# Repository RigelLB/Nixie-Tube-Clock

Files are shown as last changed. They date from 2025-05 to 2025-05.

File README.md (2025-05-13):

# Nixie-Tube-Clock
This project is based on the Easy Nixie modules made by allexoK. The following link is the Hackaday page for it: https://hackaday.io/project/192446-easynixie

The circuit itself is decently simple, the version built in the photos doesn't include the capacitors but has issues with some power supplies as the lights' striking wattage (turn on wattage) is quite above the specified 10-watt power supply. The chip used for the logic is just a generic esp32. A wire connects P27 to a plate of brass on the top of the clock. As you touch the plate it will turn on for 5 seconds (specified in code).

As a fair warning, the side usb port was put there to program the esp32 without having to take it in and out of its header pins too many times; however, if the switch isn't flipped to the correct side, no power will be supplied. An alternative is to set up the esp32 to be writable OTA.

Some improvements could be made to the electrical design. If you don't prefer having an both LED's be addressible, the posts that hold up the LED's could be used as the conductor to the second plane. 

The later goal in to add OTA code uploading to the esp32, and add a setup page (via webpage) that modifies the wifi SSID and password, time zone, turn on duration, and other features. Another thing will be to move the code to freeRTOS.
Pictures (1 of 1)
Pictures (1 of 6)

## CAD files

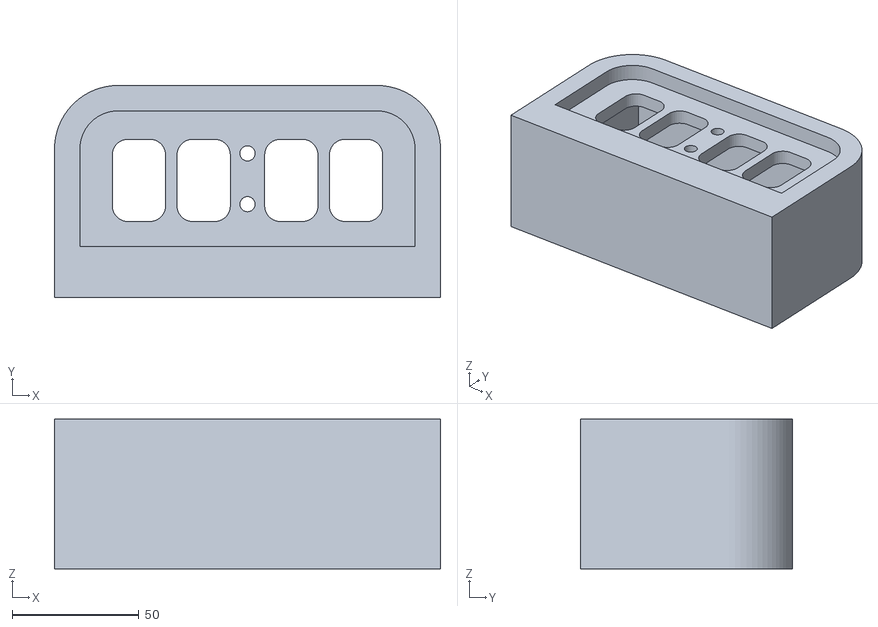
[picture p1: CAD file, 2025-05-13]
Nixie Tube Clock v12.stl
152.0 x 83.5 x 59.0

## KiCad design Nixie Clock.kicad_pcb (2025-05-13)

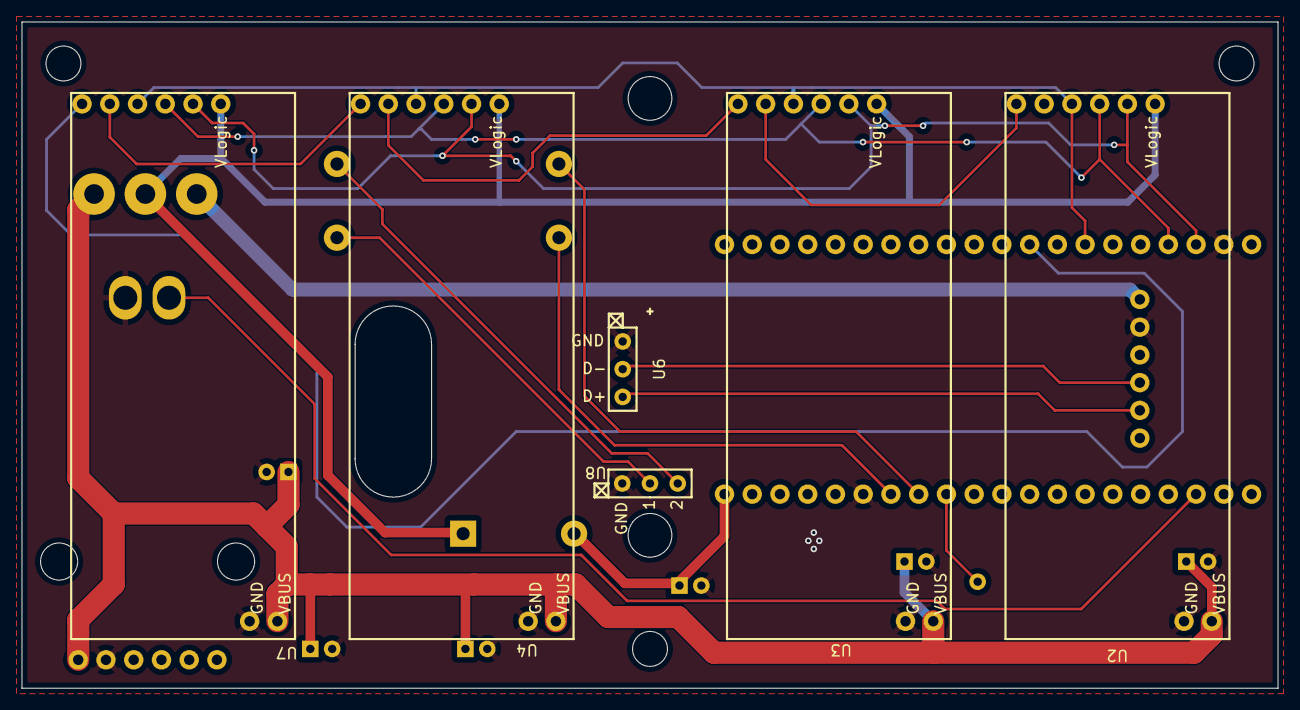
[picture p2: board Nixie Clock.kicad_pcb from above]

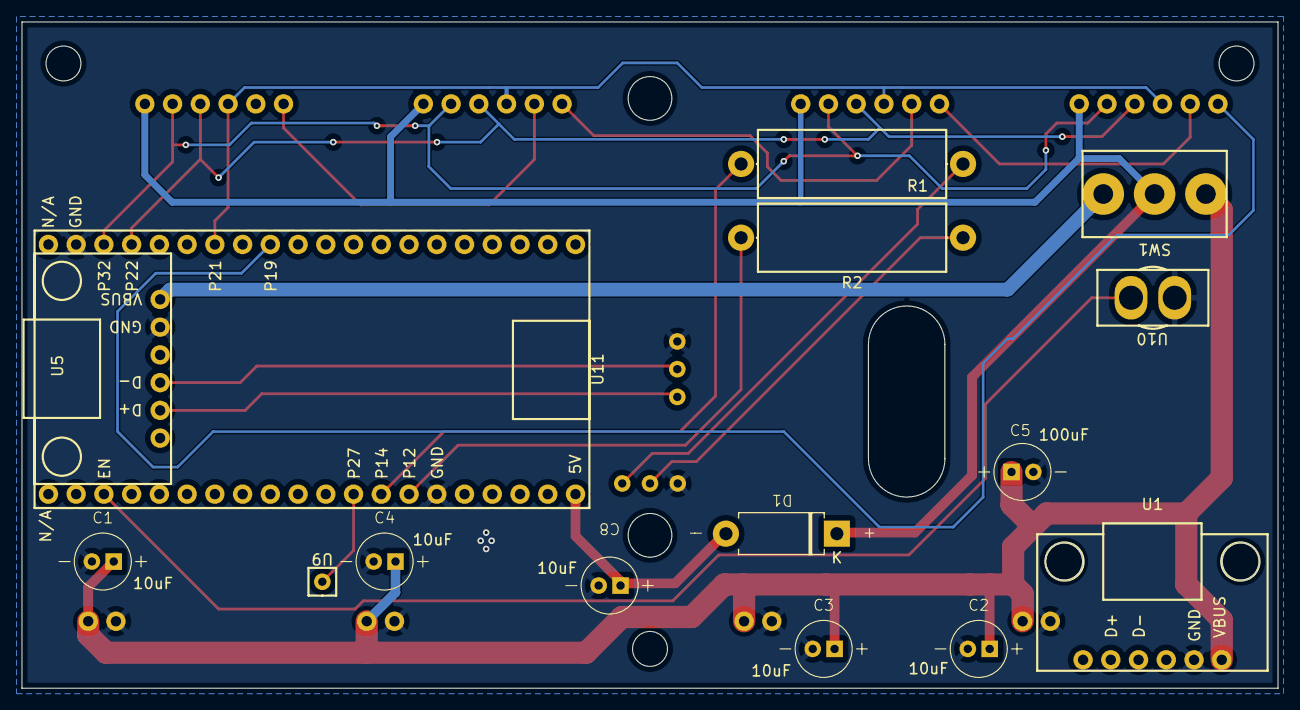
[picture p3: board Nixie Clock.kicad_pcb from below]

Board: 2 copper layers, 115.0 x 61.0 mm, 21 parts (15 on the bottom side), 20 nets.

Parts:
C1, C2, C3, C4, C8: 10uF; 100uF Capacitor
C5: 100uF; 100uF Capacitor
D1: D; Diode
R1, R2: 220; R_Axial_DIN0617_L17.0mm_D6.0mm_P20.32mm_Horizontal
SW1: SPDT Switch; ModeSwitch(41-263-0)
U1: Power Only; USBPowerPort
U2: Nixie Driver 4; NixieTubeDriver
U3: Nixie Driver 3; NixieTubeDriver
U4: Nixie Driver 2; NixieTubeDriver
U5: Data Connection; USBPowerPort
U6: 3pin Throughole; 3-Hole Throughole
U7: Nixie Driver 1; NixieTubeDriver
U8: LED Passthrough IN; LED passthrough
U9: Touch Pin; Single Pad
U10: Reset Button; SPST PushButton (SW-PB9-BB00BQE-5)
U11: ESP32 Socket; ESP32 - 40 pin socket

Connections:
GND: C1.2, C2.2, C3.2, C4.2, C5.2, C8.2, U1.2 (GND), U2.8 (GND), U3.8 (GND), U4.8 (GND), U5.2 (GND), U6.1 (GND), U7.8 (GND), U8.1 (GND), U10.1 (GND), U11.15 (GND), U11.39 (GND)
unnamed: C8.1, D1.2 (A), U11.20 (5V)
unnamed: C1.1, C2.1, C3.1, C4.1, C5.1, SW1.3 (A), U1.1 (VBUS), U2.7 (VPOWER), U3.7 (VPOWER), U4.7 (VPOWER), U7.7 (VPOWER)
unnamed: SW1.1 (C), U5.1 (VBUS)
unnamed: U2.1 (DSIN), U3.2 (DSOUT)
unnamed: U3.1 (DSIN), U4.2 (DSOUT)
unnamed: U4.1 (DSIN), U7.2 (DSOUT)
unnamed: U5.5 (D+), U6.3 (D+)
unnamed: U5.4 (D-), U6.2 (D-)
unnamed: R1.1, U8.3 (LED1)
unnamed: R2.1, U8.2 (LED2)
unnamed: U10.2 (EN), U11.3 (EN)
unnamed: R2.2, U11.14 (P12)
unnamed: R1.2, U11.13 (P14)
unnamed: U7.1 (DSIN), U11.32 (P19)
unnamed: U2.3 (STCP), U3.3 (STCP), U4.3 (STCP), U7.3 (STCP), U11.34 (P21)
unnamed: U2.4 (SHCP), U3.4 (SHCP), U4.4 (SHCP), U7.4 (SHCP), U11.37 (P22)
unnamed: U2.5 (OUT_EN), U3.5 (OUT_EN), U4.5 (OUT_EN), U7.5 (OUT_EN), U11.38 (P23)
unnamed: U9.1 (Touch), U11.12 (P27)
VCC: D1.1 (K), SW1.2 (B), U2.6 (VLOGIC), U3.6 (VLOGIC), U4.6 (VLOGIC), U7.6 (VLOGIC)

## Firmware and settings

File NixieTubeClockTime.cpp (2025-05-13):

#include <WiFi.h>
#include "time.h"
#include "EasyNixie.h"       //Nixie library
#define OUT_EN 23   //connect Pin ArduinoUNO 3 to OUT_EN
#define SHCP   22   //connect Pin ArduinoUNO 2 to SHCP
#define STCP   21   //connect Pin ArduinoUNO 6 to STCP
#define DSIN   19   //connect Pin ArduinoUNO 7 to DSIN 
#define TOUCH_PIN  27
#define LED1   14
#define LED2   12
EasyNixie en(OUT_EN,SHCP, STCP, DSIN); //Initialisation 'en' protocole
uint8_t nixieSelect;
const char* ssid = "Wifi Name";
const char* password = "Wifi password";

const char* ntpServer = "pool.ntp.org";
const long gmtOffset_sec = -18000;
const int daylightOffset_sec = 3600;
int minuteInt, hourInt, _time, day, prevDay;

char minuteChar[3], hourChar[3], dayChar[3];
unsigned long lastSetTime = 0;
const unsigned long cooldown = 5000;
bool copyIsTouched; 
bool lightsOn = false;

u16_t delayTicks = 100;
const long timeUpdateCooldown = 2000;
long lastUpdated = 0;
unsigned long now = millis();

// Connects to the wifi to sync up the time of the esp32 to the NTP server
void syncTime() {
  Serial.print("in syncTime(): ");
  Serial.println(millis());
  Serial.print("Connecting to ");
  Serial.println(ssid);
  WiFi.begin(ssid, password);
  while (WiFi.status() != WL_CONNECTED) {
    delay(500);
    Serial.print(".");
  }
  Serial.println("");
  Serial.println("WiFi connected.");
  // Init and get the time
  configTime(gmtOffset_sec, daylightOffset_sec, ntpServer);

  struct tm timeinfo;
  while (!getLocalTime(&timeinfo)) // Ensure Connection
  {
    configTime(gmtOffset_sec, daylightOffset_sec, ntpServer);
  }
  //disconnect WiFi as it's no longer needed
  WiFi.disconnect(true);
  WiFi.mode(WIFI_OFF);
}

void printLocalTime() {
  Serial.print("in printLocalTime(): ");
  Serial.println(millis());
  struct tm timeinfo;
  if (!getLocalTime(&timeinfo)) {
    Serial.println("Failed to obtain time");
    return;
  }
  Serial.print("Hour: ");
  Serial.println(&timeinfo, "%H");
  Serial.print("Minute: ");
  Serial.println(&timeinfo, "%M");
}

// Updates the time variables
void updateTime() {
  Serial.print("in updateTime(): ");
  Serial.println(millis());
  struct tm timeinfo;
  getLocalTime(&timeinfo);
  strftime(hourChar, 3, "%H", &timeinfo);
  strftime(minuteChar, 3, "%M", &timeinfo);
  strftime(dayChar, 3, "d", &timeinfo);
}

void setLEDLights(bool turnOn) {  
  char buffer[30];
  sprintf(buffer, "in setLEDLights(turnOn: %d): ", turnOn);
  Serial.print(buffer);
  Serial.println(millis());
  if (turnOn)
  {
    digitalWrite(LED1, HIGH);
    digitalWrite(LED2, HIGH);
  } else
  {
    digitalWrite(LED1, LOW);
    digitalWrite(LED2, LOW);

  }
}

void setNixieLights(bool turnOn, uint8_t select) {
  char buffer[44];
  sprintf(buffer, "in setNixieLights(turnOn: %d, select: %d): ", turnOn, select);
  Serial.print(buffer);
  Serial.println(millis());
  int a = minuteInt%10;
  int b = minuteInt/10;
  int c = hourInt%10;
  int d = hourInt/10;
  int ledLight = 0;
  if (turnOn)
  {
    ledLight = 3;
  }
  // Turns on the lights one at a time, required to reduce peak power    
  for (int i = 0; i < 4; i++)
  {
    en.SetNixie(a,ledLight,turnOn && (select & 1) && i >= 0);           //en.SetNixie Last number 
    en.SetNixie(b,ledLight,turnOn && (select & 2) && i >= 1);           //en.SetNixie Minute 
    en.SetNixie(c,ledLight,turnOn && (select & 4) && i >= 2);           //en.SetNixie Hour
    en.SetNixie(d,ledLight,turnOn && (select & 8) && i >= 3);           //en.SetNixie First Number 
    en.Latch();                      //Send your set to EaseNixie 
    delay(50);
  }
  
}

// turn the lights on from right to left going from 0 to 9 on each light
void startUpSequence() {  
  Serial.print("in startUpSequence(): ");
  Serial.println(millis());
  for (uint8_t i = 0; i < 4; i++)
  {
    for (uint8_t j = 0; j < 9; j++)
    {
      setNixieLights(false, pow(2,i)); // Could be done with bit shifting
      delay(150);
    }
    delay(200);
  }
  setLEDLights(true);
  setNixieLights(false, 15);
  delay(5000);
  setNixieLights(false, 0);
  setLEDLights(false);
}

void setup() {
  Serial.begin(115200);
  pinMode(TOUCH_PIN, INPUT);
  pinMode(LED1, OUTPUT);
  pinMode(LED2, OUTPUT);
  setNixieLights(false, 0);
  setLEDLights(false);
  syncTime(); // Call to the ntp server
  //startUpSequence(); // Currently pulls too much power for the power supply, but would function with the capacitors
  
  printLocalTime();

  struct tm timeinfo;
  getLocalTime(&timeinfo);
  day = timeinfo.tm_mday;
  prevDay = day;

}

void loop() {

  now = millis();
  if (now - lastUpdated > timeUpdateCooldown) { // Update the time every "timeUpdateCooldown"
    updateTime();
    lastUpdated = now;
  }

  int touchValue = touchRead(TOUCH_PIN);
  bool touchingNow = touchValue < 50;
  char buffer[44];
  sprintf(buffer, "TouchRead: %d", touchValue);
  Serial.println(buffer);

  if (prevDay != day) {
    syncTime();
    prevDay = day;
  }

  minuteInt = (minuteChar[0] - '0') * 10 + (minuteChar[1] - '0');
  hourInt = (hourChar[0] - '0') * 10 + (hourChar[1] - '0');

  if (touchingNow && !lightsOn && (now - lastSetTime > cooldown)) {
    lightsOn = true;
    setNixieLights(true, 15);
    setLEDLights(true);
    lastSetTime = now;

  } else if (!touchingNow && lightsOn && (now - lastSetTime > cooldown)) {
    setNixieLights(false, 0);
    setLEDLights(false);
    lightsOn = false;
    lastSetTime = now;
  }
  
  delay(delayTicks);

}
